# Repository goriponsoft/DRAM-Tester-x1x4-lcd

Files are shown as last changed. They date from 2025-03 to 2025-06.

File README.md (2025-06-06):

# DRAM Tester x1x4 lcd by Goripon Hardware
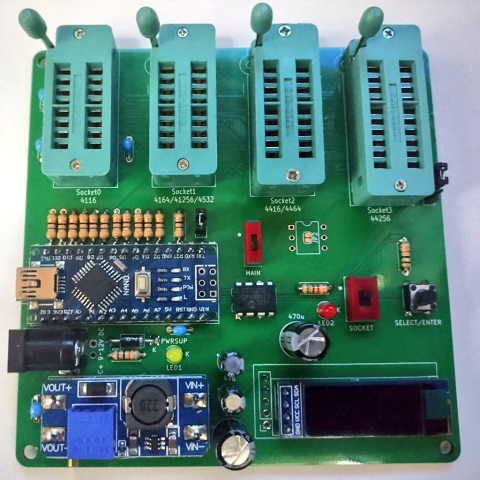
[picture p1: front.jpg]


[日本語版 README はこちら](https://github.com/goriponsoft/Dram-Tester-x1x4-lcd/blob/main/README-ja.md)

 This is a stand-alone DRAM tester compatible with 4116/4164/41256/4532/4416/4464/44256 and equipped with an LCD. Although it is not a direct fork, it is created based on [zeus074/dramtester](https://github.com/zeus074/dramtester) and [cloudree/DRAM_Tester](https://github.com/cloudree/DRAM_Tester). Thanks to the two original authors. Both of the two references are under the GPL3.0 license, so this DRAM tester will also be released under the GPL3.0 license.

 This DRAM tester was created by Goripon Hardware (the hardware division of Doujin Circle Goripon Software).

 X(old Twitter): @goriponsoft

# Components
(Check schematic/bom.xlsx as it may not match the schematic updates)
|Part Number|Parts|Quantity|
|:--|:--|--:|
|C1-C4|Unpolarized capacitor 100nF (Withstand voltage 16V or more.)|4|
|C5,C8|Polarized capacitor 470uF (Withstand voltage 16V or more.)|2|
|C6,C7|Polarized capacitor 10uF (Withstand voltage 16V or more.)|2|
|IC1|DC-DC Converter(Charge pump), 8-Pin PDIP "TJ7660"|1|
|CN1|DC Power Connector, Jack "MJ-179PH"|1|
|JP1|Pin Header 1x3 and Jumper Pin|1|
|JP2|Pin Header 1x2 and Jumper Pin|1|
|LED1|LED, D3.0mm, Yellow (Forward voltage 2.1V)|1|
|LED2|LED, D3.0mm, Green or Red (Forward voltage 2.1V)|1|
|R1-R11,R19|Resistor 47 ohm, 1/4 watt, tolerance 5%|12|
|R12,R13|Resistor 47 ohm, 1/6 watt, tolerance 5%|2|
|R14,R17|Resistor 10K ohm, 1/4 watt, tolerance 5%|2|
|R15|Resistor 1.5K ohm, 1/4 watt, required low tolerance (ex. 1%)|1|
|R16|Resistor 750 ohm, 1/4 watt, required low tolerance (ex. 1%)|1|
|R18|Resistor 5.1K ohm, 1/4 watt, tolerance 5%|1|
|S0-S1|3M Zero pressure (ZIF) socket 16pin "216-3340-00-0602J"|2|
|S2|3M Zero pressure (ZIF) socket 18pin "218-3341-00-0602J"|1|
|S3|3M Zero pressure (ZIF) socket 20pin "220-3342-00-0602J"|1|
|SW1|6x6mm Through hole & ground terminal type tactile switch "DTS-63N-V"|1|
|SW2|Switch Slide ON None ON SPDT Top Slide Thru-Hole "SS12SDP2"|1|
|SW3|Switch Slide ON None ON DPDT Top Slide Thru-Hole "SS22SDP2"|1|
|U1|Arduino Nano|1|
|U2|MT3608 DCDC Module|1|
|U3|I2C OLED Screen 0.91in. 128x32dots|1|
|-|Pin header for module installation|-|
|-|9V-12V 1A Center+ ACDC adapter|1|

# Directory
- firmware: Firmware for Arduino Nano.
- firmware/ArduinoIDE/Dram-Tester-x1x4-lcd: Firmware source code for Arduino IDE environment. You can compile and write sketches using the Arduino IDE.
- firmware/ArduinoIDE/Dram-Tester-x1x4-lcd/build: Firmware compiled binary. You can write HEX files using AVR programmer.
- firmware/PlatformIO/Dram-Tester-x1x4-lcd: Firmware source code for PlatformIO environment. You can compile using PlatformIO and write compiled binaries.
- firmware/PlatformIO/Dram-Tester-x1x4-lcd/.pio/build/Arduino_nano: Firmware compiled binary. You can write HEX files using AVR programmer.
- schematic: Schematic data for KICAD7.
- schematic/production: Gerber data for PCB ordering.

# How to assemble
Refer to the photo of the finished product on this page and solder and place the components according to the silk screen printing on the board.

For the Arduino Nano, DCDC converter board, and OLED display, first solder the headers to the components, then insert the pin headers into the board and solder them. No other special steps are required, so follow the normal assembly method for electronic circuits.

# Preparation
*For the finished products and kits we distribute, steps 1 to 6 are not necessary because the firmware is already written.

1. Connect the power supply to the board (USB connector or DC jack), turn on the main power switch, and measure the 3.3V power output of the Arduino Nano with a voltage tester and make a note of it.
2. Change "#if 0" to "#if 1" near the beginning of the setup() function in Dram-Tester-x1x4-lcd.cpp (or Dram-Tester-x1x4-lcd.ino), and replace the "3.300" part of the equation that assigns a value to the calibrationValue variable with the voltage you noted down (if you don't mind the error, you can leave it as 3.300, but the voltage check may not work correctly).
3. Connect the Arduino Nano to the PC via USB, and write the compiled sketch using the Arduino IDE, or write the HEX file using PlatformIO or an AVR writer.
4. Turn the main power switch on and off on the board, or press the reset button to start the firmware (the modified firmware will run and the voltage correction value will be written to the EEPROM).
5. Change "#if 1" in the source back to "#if 0". Note that steps 1 to 5 only need to be done the first time, and are not necessary thereafter.
6. Write the compiled sketch again using the Arduino IDE, or write the HEX file using PlatformIO or AVR writer.
7. Turn on the main power switch on the board, then turn the tri-pot resistor of the MT3608DCDC converter module while measuring the voltage with a tester to adjust it to 12V. You can also press and hold the SELECT/ENTER button while turning on or resetting the power switch to enter the setting change mode and display the voltage.
8. Set the jumper pin of JP1 (socket power LED operation). When 1-2 is shorted, the light turns on when ON, when 2-3 is shorted, the light turns on when OFF, and when the jumper pin is removed, the light turns off all the time.

# How it works
0. Connect the ACDC adapter (center positive, 9V to 12V, 1A) to the DC jack. Although it can be operated by connecting a 5V power supply or PC to the Arduino nano's USB connector, we recommend using an ACDC adapter.
1. Turn off socket power switch, then insert DRAM under test into the socket. Insert into SOCKET0 for 4116, SOCKET1 for 4164/41256/4532, SOCKET2 for 4416/4464, and SOCKET3 for 44256. *Please note that if you insert a DRAM other than 4116 type into SOCKET0, it will be damaged.
2. Turn on socket power switch, check the LCD display, and select DRAM model number by pressing SELECT/ENTER button. The socket into which the DRAM should be inserted will also be displayed on the LCD, so check that it is correct.
3. Press and hold the SELECT/ENTER button to start the test. *For safety reasons, the buttons cannot be operated while the socket power switch is off.
4. After waiting a few tens of seconds to a few minutes (depending on the amount of DRAM and test stringency settings, less if an error occurs), the results will be displayed.
5. Turn off the socket power switch and remove the tested DRAM from the socket. If you want to replace it with another DRAM after testing, please turn off the socket power switch first.

# Setting change
By holding down the SELECT/ENTER button and turning on the main power switch, you can start up in setting change mode. As with normal DRAM model selection, short press the SELECT/ENTER button to select an item, long press to confirm or change settings.

- 4bit DRAM Test: Select whether to test 4bit DRAM with priority given to speed ("Speedy") or strictly ("Strict").
- Power5V Voltage: Check the voltage of the 5V power supply and select whether to abort the test ("Check") or ignore it and continue the test ("Ignore") if the voltage is abnormal. In the case of USB power, the voltage of the power supply may drop and the test may not be performed correctly.
- Erase EEPROM: You can initialize the settings by erasing the contents of the EEPROM (values for correction, etc. remain). When erasing is complete, you will be forced to exit the settings change mode.
- View Power12V: Displays voltage of 12V power supply and voltage error. If 12V power supply voltage is not appropriate, the 4116 DRAM cannot be tested. Please reset when exiting. *Voltage cannot be displayed if the socket power is turned off.
- View Button & Power5V: Displays button test and 5V power status. Please reset when exiting.
- Save and Exit: Save the changes, exit setting change mode, and proceed to normal DRAM model number selection. Changes will not be saved unless you exit setting change mode. If you do not want to save, you can avoid saving by resetting without making a decision with this item.

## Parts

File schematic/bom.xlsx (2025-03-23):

Dram-Tester-x1x4-lcd BOM
 | Ref# | Detail | Value | Qnty
 | C1-C4 | MLC capacitor or Ceramic capacitor, radial lead, lead pitch 2.5mm | 0.1uF(100nF) 50V | 4
 | C5, C8 | ALUM capacitor, radial lead, lead pitch 3.5mm | 470uF 16V | 2
 | C6, C7 | ALUM capacitor, radial lead, lead pitch 2.0mm | 10uF 16V | 2
 | CN1 | DC jack | MJ-179PH | 1
 | D1 | General Purpose Rectifier Diode, DO-41 | 1N4007 | 1
 | IC1 | Super Charge Pump DC-to-DC Voltage Converter, DIP | TJ7660 | 1
 | JP1 | Pin Header 1x3 | - | 1
 | JP2 | Pin Header 1x2 | - | 1
 | LED1 | LED, D3.0mm, Yellow | OSY5JA3Z74A | 1
 | LED2 | LED, D3.0mm, Green | OSG5TA3Z74A | 1
 | R1-R13 | Register 1/4W, tolerance 5% | 47 ohm | 13
 | R19 | Register 1/4W, tolerance 5% | 47 ohm | 1
 | R14, R17 | Register 1/4W, tolerance 5% | 10K ohm | 2
 | R15 | Register 1/4W, low tolerance | 1.5K ohm | 1
 | R16 | Register 1/4W, low tolerance | 750 ohm | 1
 | R18 | Register 1/4W, tolerance 5% | 5.1K ohm | 1
 | S0-S1 | Zero pressure (ZIF) socket 16pin | 216-3340-00-0602J | 2
 | S2 | Zero pressure (ZIF) socket 18pin | 218-3341-00-0602J | 1
 | S3 | Zero pressure (ZIF) socket 20pin | 220-3342-00-0602J | 1
 | SW1 | 6x6mm tactile switch, through hole | DTS-63N-V | 1
 | SW2 | Slide switch, through hole, SPDT ON-ON | SS12SDP2 | 1
 | SW3 | Slide switch, through hole, DPDT ON-ON | SS22SDP2 | 1
 | U1 | Arduino Nano | - | 1
 | U2 | MT3608 DC-DC converter module | - | 1
 | U3 | OLED Screen 0.91inch, I2C SSD1306 controller, 128x32 dot | - | 1

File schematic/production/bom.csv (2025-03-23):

Designator | Footprint | Quantity | Value | LCSC Part #
C1, C2, C3, C4 | C_Disc_D3.4mm_W2.1mm_P2.50mm | 4 | 0.1u
C5, C8 | CP_Radial_D8.0mm_P3.50mm | 2 | 470u
C6, C7 | CP_Radial_D5.0mm_P2.00mm | 2 | 10u
CN1 | MJ179PH | 1 | MJ-179PH
D1 | D_DO-41_SOD81_P10.16mm_Horizontal | 1 | 1N4007
IC1 | DIP8_300mil_FineLongPad | 1 | TJ7660
JP1 | PinHeader_1x03_P2.54mm_Vertical | 1 | LEDTYP
LED1 | LED_D3.0mm | 1 | Yellow
LED2 | LED_D3.0mm | 1 | SCKTPW
R1, R10, R11, R12, R13, R2, R3, R4, R5, R6, R7, R8, R9 | R_Axial_DIN0207_L6.3mm_D2.5mm_P7.62mm_Horizontal | 13 | 47
R14, R17 | R_Axial_DIN0207_L6.3mm_D2.5mm_P7.62mm_Horizontal | 2 | 10K
R15 | R_Axial_DIN0207_L6.3mm_D2.5mm_P7.62mm_Horizontal | 1 | 1.5k
R16 | R_Axial_DIN0207_L6.3mm_D2.5mm_P7.62mm_Horizontal | 1 | 750
R18 | R_Axial_DIN0207_L6.3mm_D2.5mm_P7.62mm_Horizontal | 1 | 5.1K
S0, S1 | DIP_Socket-16_W4.3_W5.08_W7.62_W10.16_W10.9_3M_216-3340-00-0602J | 2 | ZIF Socket 16pin
S2 | DIP_Socket-18_W4.3_W5.08_W7.62_W10.16_W10.9_3M_218-3341-00-0602J | 1 | ZIF Socket 18pin
S3 | DIP_Socket-20_W4.3_W5.08_W7.62_W10.16_W10.9_3M_220-3342-00-0602J | 1 | ZIF Socket 20pin
SW1 | DTS63NV | 1 | DTS-63N-V
SW2 | SS12SDP2 | 1 | SS12SDP2
SW3 | SS22SDP2 | 1 | SS22SDP2
U1 | Arduino_Nano | 1 | Arduino Nano
U2 | MT3608_DCDC_Module | 1 | MT3608 DCDC Module
U3 | I2C_OLED_0.91in_128x32 | 1 | I2C OLED Screen 0.91inch 128x32dot

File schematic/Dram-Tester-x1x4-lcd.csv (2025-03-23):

Source: | Y:\Project\Dram-Tester-x1x4-lcd\Dram-Tester-x1x4-lcd.kicad_sch
Date: | 2025/03/17 20:05:09
Tool: | Eeschema 7.0.11
Generator: | C:\Program Files\KiCad\7.0\bin\scripting\plugins/bom_csv_grouped_by_value_with_fp.py
Component Count: | 42
Ref | Qnty | Value | Cmp name | Footprint | Description | Vendor | DNP
C1, C2, C3, C4 | 4 | 0.1u | C_Small | Capacitor_THT:C_Disc_D3.4mm_W2.1mm_P2.50mm | Unpolarized capacitor, small symbol
C5, C8 | 2 | 470u | C_Polarized_Small | Capacitor_THT:CP_Radial_D8.0mm_P3.50mm | Polarized capacitor, small symbol
C6, C7 | 2 | 10u | C_Polarized_Small | Capacitor_THT:CP_Radial_D5.0mm_P2.00mm | Polarized capacitor, small symbol
CN1 | 1 | MJ-179PH | MJ-179PH | ProjectLibrary:MJ179PH | DC Power Connector, Jack, 4 A, 1.95 mm, PCB Mount, Through Hole, J=Center-pin/S=Outer-contact
D1 | 1 | 1N4007 | 1N4007 | Diode_THT:D_DO-41_SOD81_P10.16mm_Horizontal | 1000V 1A General Purpose Rectifier Diode, DO-41
IC1 | 1 | TJ7660 | TC7660SCPA | ProjectLibrary:DIP8_300mil_FineLongPad | Microchip TC7660SCPA, DC-DC Converter, 8-Pin PDIP
JP1 | 1 | LEDTYP | Jumper_3_Open | Connector_PinHeader_2.54mm:PinHeader_1x03_P2.54mm_Vertical | Jumper, 3-pole, both open
LED1 | 1 | Yellow | LED_Small_Filled | LED_THT:LED_D3.0mm | Light emitting diode, small symbol, filled shape
LED2 | 1 | SCKTPW | LED_Small_Filled | LED_THT:LED_D3.0mm | Light emitting diode, small symbol, filled shape
R1, R2, R3, R4, R5, R6, R7, R8, R9, R10, R11, R12, R13 | 13 | 47 | R_Small | ProjectLibrary:R_Axial_DIN0207_L6.3mm_D2.5mm_P7.62mm_Horizontal | Resistor, small symbol
R14, R17 | 2 | 10K | R_Small | Resistor_THT:R_Axial_DIN0207_L6.3mm_D2.5mm_P7.62mm_Horizontal | Resistor, small symbol
R15 | 1 | 1.5k | R_Small | Resistor_THT:R_Axial_DIN0207_L6.3mm_D2.5mm_P7.62mm_Horizontal | Resistor, small symbol
R16 | 1 | 750 | R_Small | Resistor_THT:R_Axial_DIN0207_L6.3mm_D2.5mm_P7.62mm_Horizontal | Resistor, small symbol
R18 | 1 | 5.1K | R_Small | Resistor_THT:R_Axial_DIN0207_L6.3mm_D2.5mm_P7.62mm_Horizontal | Resistor, small symbol
S0, S1 | 2 | ZIF Socket 16pin | DRAM_256Kx1 | Socket:DIP_Socket-16_W4.3_W5.08_W7.62_W10.16_W10.9_3M_216-3340-00-0602J
S2 | 1 | ZIF Socket 18pin | DRAM_64Kx4 | Socket:DIP_Socket-18_W4.3_W5.08_W7.62_W10.16_W10.9_3M_218-3341-00-0602J
S3 | 1 | ZIF Socket 20pin | DRAM_256Kx4 | Socket:DIP_Socket-20_W4.3_W5.08_W7.62_W10.16_W10.9_3M_220-3342-00-0602J
SW1 | 1 | DTS-63N-V | DTS-63N-V | ProjectLibrary:DTS63NV | 6x6 Through Hole & Ground Terminal Type,TS 6MM V H=7.0 160gf BULK
SW2 | 1 | SS12SDP2 | SS12SDP2 | ProjectLibrary:SS12SDP2 | Switch, Slide,Sub Miniature,Top Actuated,SPDT, On-none-On
SW3 | 1 | SS22SDP2 | SS22SDP2 | ProjectLibrary:SS22SDP2 | Switch Slide ON None ON DPDT Top Slide 0.1A 30VDC 10000Cycles PC Pins Thru-Hole
U1 | 1 | Arduino Nano | Arduino_Nano_v3.x | Module:Arduino_Nano | Arduino Nano v3.x
U2 | 1 | MT3608 DCDC Module | MT3608_DCDC_Module | ProjectLibrary:MT3608_DCDC_Module
U3 | 1 | I2C OLED Screen 0.91inch 128x32dot | I2C_OLED_Screen_0.91_128x32 | ProjectLibrary:I2C_OLED_0.91in_128x32 | I2C OLED Screen 0.91inch 128x32dot SSD1306 controller

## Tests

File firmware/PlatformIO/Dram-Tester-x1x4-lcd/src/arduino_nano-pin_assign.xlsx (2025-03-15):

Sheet: pin assign(1)
assign | Arduino nano |  |  |  | assign
DRAM-A5 | PB5 | D13 | D12 | PB4 | DRAM-A4
3V3 | - | 3V3 | ~D11 | PB3 | DRAM-A3
no | - | AREF | ~D10 | PB2 | DRAM-A2
DRAM-DQ0/Q | PC0 | A0/D14 | ~D9 | PB1 | DRAM-A1
DRAM-DQ1/D | PC1 | A1/D15 | D8 | PB0 | DRAM-A0
DRAM-DQ2 | PC2 | A2/D16 | D7 | PD7 | DRAM-A8
DRAM-DQ3 | PC3 | A3/D17 | ~D6 | PD6 | DRAM-A7
I2C | PC4 | A4/D18 | ~D5 | PD5 | DRAM-A6
I2C | PC5 | A5/D19 | D4 | PD4 | DRAM-/RAS
Button/3V3 monitoring | - | A6 | ~D3 | PD3 | DRAM-/CAS
12V monitoring | - | A7 | D2 | PD2 | DRAM-/W
DRAM Power Supply | - | +5V | GND | - | (DRAM-/OE)
no | PC6 | RESET | RESET | PC6 | no
GND | - | GND | D0/RX | PD0 | no
AC Adaptor | - | VIN | D1/TX | PD1 | (DRAM-A9)

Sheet: pin assign(2)
PC0 | DRAM-DQ0/Q
PC1 | DRAM-DQ1/D
PC2 | DRAM-DQ2
PC3 | DRAM-DQ3
PC4 | I2C-SDA
PC5 | I2C-SCL
PC6 | (RESET)
PC7 | -
PD0 | (no assign)
PD1 | DRAM-A9
PD2 | DRAM-/W
PD3 | DRAM-/CAS
PD4 | DRAM-/RAS
PD5 | DRAM-A6
PD6 | DRAM-A7
PD7 | DRAM-A8
PB0 | DRAM-A0
PB1 | DRAM-A1
PB2 | DRAM-A2
PB3 | DRAM-A3
PB4 | DRAM-A4
PB5 | DRAM-A5
PB6 | (XTAL)
PB7 | (XTAL)

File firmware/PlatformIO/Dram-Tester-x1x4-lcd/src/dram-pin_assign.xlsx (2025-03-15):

4116 |  |  |  |  |  | 4164 typeA |  |  |  |  |  | 4416 |  |  |  |  |  | 44256
-5V | VBB | 1 | 16 | VSS | GND | ROW8/COL8 | NC | 1 | 16 | VSS | GND | GND | /G | 1 | 18 | VSS | GND | - | DQ1 | 1 | 20 | VSS | GND
- | D | 2 | 15 | /CAS | - | - | D | 2 | 15 | /CAS | - | - | DQ1 | 2 | 17 | DQ4 | - | - | DQ2 | 2 | 19 | DQ4 | -
- | /W | 3 | 14 | Q | - | - | /W | 3 | 14 | Q | - | - | DQ2 | 3 | 16 | /CAS | - | - | /W | 3 | 18 | DQ3 | -
- | /RAS | 4 | 13 | A6 | ROW6/COL6 | - | /RAS | 4 | 13 | A6 | ROW6/COL6 | - | /W | 4 | 15 | DQ3 | - | - | /RAS | 4 | 17 | /CAS | -
ROW0/COL0 | A0 | 5 | 12 | A3 | ROW3/COL3 | ROW0/COL0 | A0 | 5 | 12 | A3 | ROW3/COL3 | - | /RAS | 5 | 14 | A0 | ROW0 | - | NC | 5 | 16 | /G | GND
ROW2/COL2 | A2 | 6 | 11 | A4 | ROW4/COL4 | ROW2/COL2 | A2 | 6 | 11 | A4 | ROW4/COL4 | ROW6/COL5 | A6 | 6 | 13 | A1 | ROW1/COL0 | ROW0/COL0 | A0 | 6 | 15 | A8 | ROW8/COL8
ROW1/COL1 | A1 | 7 | 10 | A5 | ROW5/COL5 | ROW1/COL1 | A1 | 7 | 10 | A5 | ROW5/COL5 | ROW5/COL4 | A5 | 7 | 12 | A2 | ROW2/COL1 | ROW1/COL1 | A1 | 7 | 14 | A7 | ROW7/COL7
+12V | VDD | 8 | 9 | VCC | +5V | +5V | VDD | 8 | 9 | A7 | ROW7/COL7 | ROW4/COL3 | A4 | 8 | 11 | A3 | ROW3/COL2 | ROW2/COL2 | A2 | 8 | 13 | A6 | ROW6/COL6
 |  |  |  |  |  |  |  |  |  |  |  | +5V | VDD | 9 | 10 | A7 | ROW7 | ROW3/COL3 | A3 | 9 | 12 | A5 | ROW5/COL5
 |  |  |  |  |  | 4164 typeB |  |  |  |  |  |  |  |  |  |  |  | +5V | VCC | 10 | 11 | A4 | ROW4/COL4
 |  |  |  |  |  | ROW8=H/COL8=H | /RFSH | 1 | 16 | VSS | GND | 4464
 |  |  |  |  |  | - | D | 2 | 15 | /CAS | - | GND | /G | 1 | 18 | VSS | GND | 4400
 |  |  |  |  |  | - | /W | 3 | 14 | Q | - | - | DQ1 | 2 | 17 | DQ4 | - | - | DQ1 | 1 | 20 | VSS | GND
 |  |  |  |  |  | - | /RAS | 4 | 13 | A6 | ROW6/COL6 | - | DQ2 | 3 | 16 | /CAS | - | - | DQ2 | 2 | 19 | DQ4 | -
 |  |  |  |  |  | ROW0/COL0 | A0 | 5 | 12 | A3 | ROW3/COL3 | - | /W | 4 | 15 | DQ3 | - | - | /W | 3 | 18 | DQ3 | -
 |  |  |  |  |  | ROW2/COL2 | A2 | 6 | 11 | A4 | ROW4/COL4 | - | /RAS | 5 | 14 | A0 | ROW0/COL0 | - | /RAS | 4 | 17 | /CAS | -
 |  |  |  |  |  | ROW1/COL1 | A1 | 7 | 10 | A5 | ROW5/COL5 | ROW6/COL6 | A6 | 6 | 13 | A1 | ROW1/COL1 | ROW9/COL9 | A9 | 5 | 16 | /G | GND
 |  |  |  |  |  | +5V | VDD | 8 | 9 | A7 | ROW7/COL7 | ROW5/COL5 | A5 | 7 | 12 | A2 | ROW2/COL2 | ROW0/COL0 | A0 | 6 | 15 | A8 | ROW8/COL8
 |  |  |  |  |  |  |  |  |  |  |  | ROW4/COL4 | A4 | 8 | 11 | A3 | ROW3/COL3 | ROW1/COL1 | A1 | 7 | 14 | A7 | ROW7/COL7
 |  |  |  |  |  | 41256 |  |  |  |  |  | +5V | VDD | 9 | 10 | A7 | ROW7/COL7 | ROW2/COL2 | A2 | 8 | 13 | A6 | ROW6/COL6
 |  |  |  |  |  | ROW8/COL8 | A8 | 1 | 16 | VSS | GND |  |  |  |  |  |  | ROW3/COL3 | A3 | 9 | 12 | A5 | ROW5/COL5
 |  |  |  |  |  | - | D | 2 | 15 | /CAS | - |  |  |  |  |  |  | +5V | VCC | 10 | 11 | A4 | ROW4/COL4
 |  |  |  |  |  | - | /W | 3 | 14 | Q | -
 |  |  |  |  |  | - | /RAS | 4 | 13 | A6 | ROW6/COL6
 |  |  |  |  |  | ROW0/COL0 | A0 | 5 | 12 | A3 | ROW3/COL3
 |  |  |  |  |  | ROW2/COL2 | A2 | 6 | 11 | A4 | ROW4/COL4
 |  |  |  |  |  | ROW1/COL1 | A1 | 7 | 10 | A5 | ROW5/COL5
 |  |  |  |  |  | +5V | VDD | 8 | 9 | A7 | ROW7/COL7
 |  |  |  |  |  | 4532L
 |  |  |  |  |  | ROW8/COL8 | NC | 1 | 16 | VSS | GND
 |  |  |  |  |  | - | D | 2 | 15 | /CAS | -
 |  |  |  |  |  | - | /W | 3 | 14 | Q | -
 |  |  |  |  |  | - | /RAS | 4 | 13 | A6 | ROW6/COL6
 |  |  |  |  |  | ROW0/COL0 | A0 | 5 | 12 | A3 | ROW3/COL3
 |  |  |  |  |  | ROW2/COL2 | A2 | 6 | 11 | A4 | ROW4/COL4
 |  |  |  |  |  | ROW1/COL1 | A1 | 7 | 10 | A5 | ROW5/COL5
 |  |  |  |  |  | +5V | VDD | 8 | 9 | A7 | ROW7/COL7=L
 |  |  |  |  |  | 4532H
 |  |  |  |  |  | ROW8/COL8 | NC | 1 | 16 | VSS | GND
 |  |  |  |  |  | - | D | 2 | 15 | /CAS | -
 |  |  |  |  |  | - | /W | 3 | 14 | Q | -
 |  |  |  |  |  | - | /RAS | 4 | 13 | A6 | ROW6/COL6
 |  |  |  |  |  | ROW0/COL0 | A0 | 5 | 12 | A3 | ROW3/COL3
 |  |  |  |  |  | ROW2/COL2 | A2 | 6 | 11 | A4 | ROW4/COL4
 |  |  |  |  |  | ROW1/COL1 | A1 | 7 | 10 | A5 | ROW5/COL5
 |  |  |  |  |  | +5V | VDD | 8 | 9 | A7 | ROW7/COL7=H

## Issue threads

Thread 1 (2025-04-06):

Just a question...

solidhit2, 2025-04-06:
I came across this project recently and I'm about to order the PCB from PCBWay. Is there something I should be careful of before I make my order? Finally, I would like to know if it supports the Marching Memory testing algorithms or if you intend to implement such algorithms in the future? By the way, I wish every success for this project... the retro community needs a memory tester for as many old memory chips as possible!

solidhit2, 2025-04-28:
Not a real issue!

Closed 2025-04-28.

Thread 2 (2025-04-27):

Wrong voltage measurement...

solidhit2, 2025-04-27:
I assembled the tester soon after my PCBs arrived from PCBWAY. When I tried to run the tester I received a message that 5V failed. Measuring right at the socket with a multi-meter, I get 5V exactly (I also get 11.94 for the 12V and -5V exactly for the -5V for socket0). I went to the settings menu and deactivated the 5V check and the tester works. In the settings menu I saw that Arduino measures my 5V as 4.5V and my 12V as 10.6V. Why is this happening, is there anything I can do to help it measure right?

For your information, my Arduino nano is not the original, I bought it from ALIEXPRESS as an "Arduino nano v3". Other than that the tests seem to work fine although I don't have any bad chips at the moment.

Lastly, I use a PD trigger module to power the PCB similar to PDT006. It produces a very clean voltage and operates at 9V exactly.

I'd be grateful for any advice!

goriponsoft, 2025-04-28:
Sorry.

The +5V power supply voltage is measured using a value corrected based on the Arduino Nano's +3.3V power supply voltage as the standard, but if nothing is done, it will operate as if +3.3V is the standard value, which may result in an incorrect voltage measurement.

To operate correctly if the measurement is incorrect, it is necessary to write the value used for voltage correction to the EEPROM, but this procedure was not mentioned.

I have added instructions for writing the values   needed for voltage correction to the EEPROM in the Preparation section of the README, so please refer to that.

________________________________
差出人: solidhit2 ***@***.***>
送信日時: 2025年4月28日 6:31
宛先: goriponsoft/DRAM-Tester-x1x4-lcd ***@***.***>
CC: Subscribed ***@***.***>
件名: [goriponsoft/DRAM-Tester-x1x4-lcd] Wrong voltage measurement... (Issue #2)

[https://avatars.githubusercontent.com/u/157960411?s=20&v=4]solidhit2 created an issue (goriponsoft/DRAM-Tester-x1x4-lcd#2)<https://github.com/goriponsoft/DRAM-Tester-x1x4-lcd/issues/2>

I assembled the tester soon after my PCBs arrived from PCBWAY. When I tried to run the tester I received a message that 5V failed. Measuring right at the socket with a multi-meter, I get 5V exactly (I also get 11.94 for the 12V and -5V exactly for the -5V for socket0). I went to the settings menu and deactivated the 5V check and the tester works. In the settings menu I saw that Arduino measures my 5V as 4.5V and my 12V as 10.6V. Why is this happening, is there anything I can do to help it measure right?

For your information, my Arduino nano is not the original, I bought it from ALIEXPRESS as an "Arduino nano v3". Other than that the tests seem to work fine although I don't have any bad chips at the moment.

Lastly, I use a PD trigger module to power the PCB similar to PDT006. It produces a very clean voltage and operates at 9V exactly.

I'd be grateful for any advice!

—
Reply to this email directly, view it on GitHub<https://github.com/goriponsoft/DRAM-Tester-x1x4-lcd/issues/2>, or unsubscribe<https://github.com/notifications/unsubscribe-auth/AAX3SQYVHZN5VGP6ZUQM5DT23VEBRAVCNFSM6AAAAAB37AZWKGVHI2DSMVQWIX3LMV43ASLTON2WKOZTGAZDGMZTGM4DQMY>.
You are receiving this because you are subscribed to this thread.Message ID: ***@***.***>

solidhit2, 2025-04-28:
Thank you for the quick response. I did what was mentioned in the readme and now the tester detects voltage properly. Just one remark. In your code you have the line "#define VOLTAGE_3V3_MAX 3.6". In my case, two of my five nano boards measured ~3.68V which caused your code to ignore my value and revert to 3.3V. I had to change the above line to "#define VOLTAGE_3V3_MAX 3.7". After that, everything worked as it should.

Since you went to the trouble of explaining how to make nano properly measure voltage, perhaps you could add some clarifications about J1 and J2 located below the oled display (I figured that out myself) and JP2 which enables A9. What is A9, when do we close the jumper and when we don't etc...

I hope in the future you may be able to add the advanced marching algorithm which can catch any combination of memory errors.

goriponsoft, 2025-04-29:
It's strange that 3.3V is measured at 3.6V or higher.

I think an error of 10% or more is abnormal (+10% voltage is 3.63V), but there are no devices on the board that directly use the 3.3V power supply, so it shouldn't be a problem.

A9 is a signal used to test 1M x 4bit (4400 type) DRAM with Socket3, and this function is disabled in the published source code.

A9 is also used as the TX signal (PD1) used for USB connection to the PC, so it was assumed that it would be open when writing firmware, but so far there have been no problems with writing firmware even if it is closed.

To be able to test 4400 type DRAM, uncomment the following line near the beginning of "Dram-Tester-x1x4-lcd.h" (or "Dram-Tester-x1x4-lcd.ino") and build it.

//#define _BUS_A9_ENABLE
//#define _4M_DRAM_ENABLE

Thank you for your request for a test algorithm. We will consider responding to your request, but since this tester is open source, you can also modify it yourself.

________________________________
差出人: solidhit2 ***@***.***>
送信日r: 2025年4月29日 0:52
宛先: goriponsoft/DRAM-Tester-x1x4-lcd ***@***.***>
CC: goriponsoft ***@***.***>; Comment ***@***.***>
件名: Re: [goriponsoft/DRAM-Tester-x1x4-lcd] Wrong voltage measurement... (Issue #2)

[https://avatars.githubusercontent.com/u/157960411?s=20&v=4]solidhit2 left a comment (goriponsoft/DRAM-Tester-x1x4-lcd#2)<https://github.com/goriponsoft/DRAM-Tester-x1x4-lcd/issues/2#issuecomment-2835713360>

Thank you for the quick response. I did what was mentioned in the readme and now the tester detects voltage properly. Just one remark. In your code you have the line "#define VOLTAGE_3V3_MAX 3.6". In my case, two of my five nano boards measured ~3.68V which caused your code to ignore my value and revert to 3.3V. I had to change the above line to "#define VOLTAGE_3V3_MAX 3.7". After that, everything worked as it should.

Since you went to the trouble of explaining how to make nano properly measure voltage, perhaps you could add some clarifications about J1 and J2 located below the oled display (I figured that out myself) and JP2 which enables A9. What is A9, when do we close the jumper and when we don't etc...

I hope in the future you may be able to add the advanced marching algorithm which can catch any combination of memory errors.

―
Reply to this email directly, view it on GitHub<https://github.com/goriponsoft/DRAM-Tester-x1x4-lcd/issues/2#issuecomment-2835713360>, or unsubscribe<https://github.com/notifications/unsubscribe-auth/AAX3SQ3HROHPBEXWIQ6NWKL23ZFELAVCNFSM6AAAAAB37AZWKGVHI2DSMVQWIX3LMV43OSLTON2WKQ3PNVWWK3TUHMZDQMZVG4YTGMZWGA>.
You are receiving this because you commented.Message ID: ***@***.***>

Closed 2025-04-29.

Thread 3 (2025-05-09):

Negative voltage possibly present even when socket power switch is off.

solidhit2, 2025-05-09:
I've been using the tester to test more than a 100 41256 memory chips and and I came across this issue. The way I work is: socket power off, put the 41256 chip in socket1, socket power on, button to start testing. This happens in quick succession because there are a lot of chips waiting to be tested. Well, testing one particular chip, I inserted the chip in socket 0 with socket power off! I instantly realized what I had done and took the chip out of socket0, inserted in in socket1, turned socket power on, started the test and the chip was bad. I found it suspicious so I tested the voltages in socket0 soon as I turned off socket power. Well, 5v and 12v were instantly 0 but with -5v, I measured ~-4.x. Turns out, -5v drop to 0 very slowly.

goriponsoft, 2025-05-12:
I was not aware of this behavior.

Maybe there are too many electrolytic capacitors.
Properly removing one or both of the two 470uF electrolytic capacitors may improve the situation.
________________________________
差出人: solidhit2 ***@***.***>
送信日時: 2025年5月9日 23:52
宛先: goriponsoft/DRAM-Tester-x1x4-lcd ***@***.***>
CC: Subscribed ***@***.***>
件名: [goriponsoft/DRAM-Tester-x1x4-lcd] Negative voltage possibly present even when socket power switch is off. (Issue #3)

[https://avatars.githubusercontent.com/u/157960411?s=20&v=4]solidhit2 created an issue (goriponsoft/DRAM-Tester-x1x4-lcd#3)<https://github.com/goriponsoft/DRAM-Tester-x1x4-lcd/issues/3>

I've been using the tester to test more than a 100 41256 memory chips and and I came across this issue. The way I work is: socket power off, put the 41256 chip in socket1, socket power on, button to start testing. This happens in quick succession because there are a lot of chips waiting to be tested. Well, testing one particular chip, I inserted the chip in socket 0 with socket power off! I instantly realized what I had done and took the chip out of socket0, inserted in in socket1, turned socket power on, started the test and the chip was bad. I found it suspicious so I tested the voltages in socket0 soon as I turned off socket power. Well, 5v and 12v were instantly 0 but with -5v, I measured ~-4.x. Turns out, -5v drop to 0 very slowly.

—
Reply to this email directly, view it on GitHub<https://github.com/goriponsoft/DRAM-Tester-x1x4-lcd/issues/3>, or unsubscribe<https://github.com/notifications/unsubscribe-auth/AAX3SQ3TM64VPWRNDG7D75T25S6JLAVCNFSM6AAAAAB4ZITHD2VHI2DSMVQWIX3LMV43ASLTON2WKOZTGA2TENBSGEYDSMY>.
You are receiving this because you are subscribed to this thread.Message ID: ***@***.***>

solidhit2, 2025-05-12:
OK, but should they be removed? Aren't they used for other things?

solidhit2, 2025-05-14:
Thank you for your response, let me tell you what I have...

I have the latest revision of the board, there are no capacitor names on the silkscreen, so I will try to figure things out taking measurements on an actual PCB and studying the schematic.

My board has positions for four electrolytic caps, two are 10uf and the other two are 470uf as written on the silkscreen.

I have a 470uf cap. between Arduino 5VDC output and GND, according to the schematic, this is C5.

I have a 10uf cap. between the VOUT of TJ7660 and GND. According to the schematic, this is C6.

I have a 10uf cap. between the CAP+ and CAP-  legs of TJ7660, according to the schematic, this is C7.

I have a 470uf cap. between PIN2 of the socket power switch and GND, according to the schematic, this is C8.

These are all. My C6 is already 10uf, I have no caps. at 47uf and I don't have a C9.

solidhit2, 2025-05-15:
I took the liberty and removed my C8 from the board as it matched the description of your C9 capacitor. The behaviour of the -5v when switch power goes off, barely changed, still residual voltage ~3-4v dropping slowly. Also, now whenever I switch the socket power on, Arduino resets (one time) before it becomes responsive again. This happens whether there is a chip in a socket or not!

goriponsoft, 2025-06-06:
If the board resets when the socket switch is turned on, the current capacity of the ACDC adapter may be insufficient. A current capacity of 1A (1000mA) or more is required.

The power supplied from the Arduino Nano's USB connector cannot meet this current capacity, so an ACDC adapter is required (USB can only supply a maximum of 500mA).

I added a 470uF electrolytic capacitor to solve this problem, but it had no effect, so it is now a candidate for removal.

Regarding the capacitor part numbers, we were explaining about the Revision 2 board, but the version currently published on GitHub is Revision 3, so the 47uF electrolytic capacitor has been changed to 10uF and other minor corrections have been made.
________________________________
差出人: solidhit2 ***@***.***>
送信日r: 2025年5月16日 6:03
宛先: goriponsoft/DRAM-Tester-x1x4-lcd ***@***.***>
CC: goriponsoft ***@***.***>; Comment ***@***.***>
件名: Re: [goriponsoft/DRAM-Tester-x1x4-lcd] Negative voltage possibly present even when socket power switch is off. (Issue #3)

[https://avatars.githubusercontent.com/u/157960411?s=20&v=4]solidhit2 left a comment (goriponsoft/DRAM-Tester-x1x4-lcd#3)<https://github.com/goriponsoft/DRAM-Tester-x1x4-lcd/issues/3#issuecomment-2885048256>

I took the liberty and removed my C8 from the board as it matched the description of your C9 capacitor. The behaviour of the -5v when switch power goes off, barely changed, still residual voltage ~3-4v dropping slowly. Also, now whenever I switch the socket power on, Arduino resets (one time) before it becomes responsive again. This happens whether there is a chip in a socket or not!

―
Reply to this email directly, view it on GitHub<https://github.com/goriponsoft/DRAM-Tester-x1x4-lcd/issues/3#issuecomment-2885048256>, or unsubscribe<https://github.com/notifications/unsubscribe-auth/AAX3SQ2EKMBA3WL3FFRPAVL26T6LJAVCNFSM6AAAAAB4ZITHD2VHI2DSMVQWIX3LMV43OSLTON2WKQ3PNVWWK3TUHMZDQOBVGA2DQMRVGY>.
You are receiving this because you commented.Message ID: ***@***.***>

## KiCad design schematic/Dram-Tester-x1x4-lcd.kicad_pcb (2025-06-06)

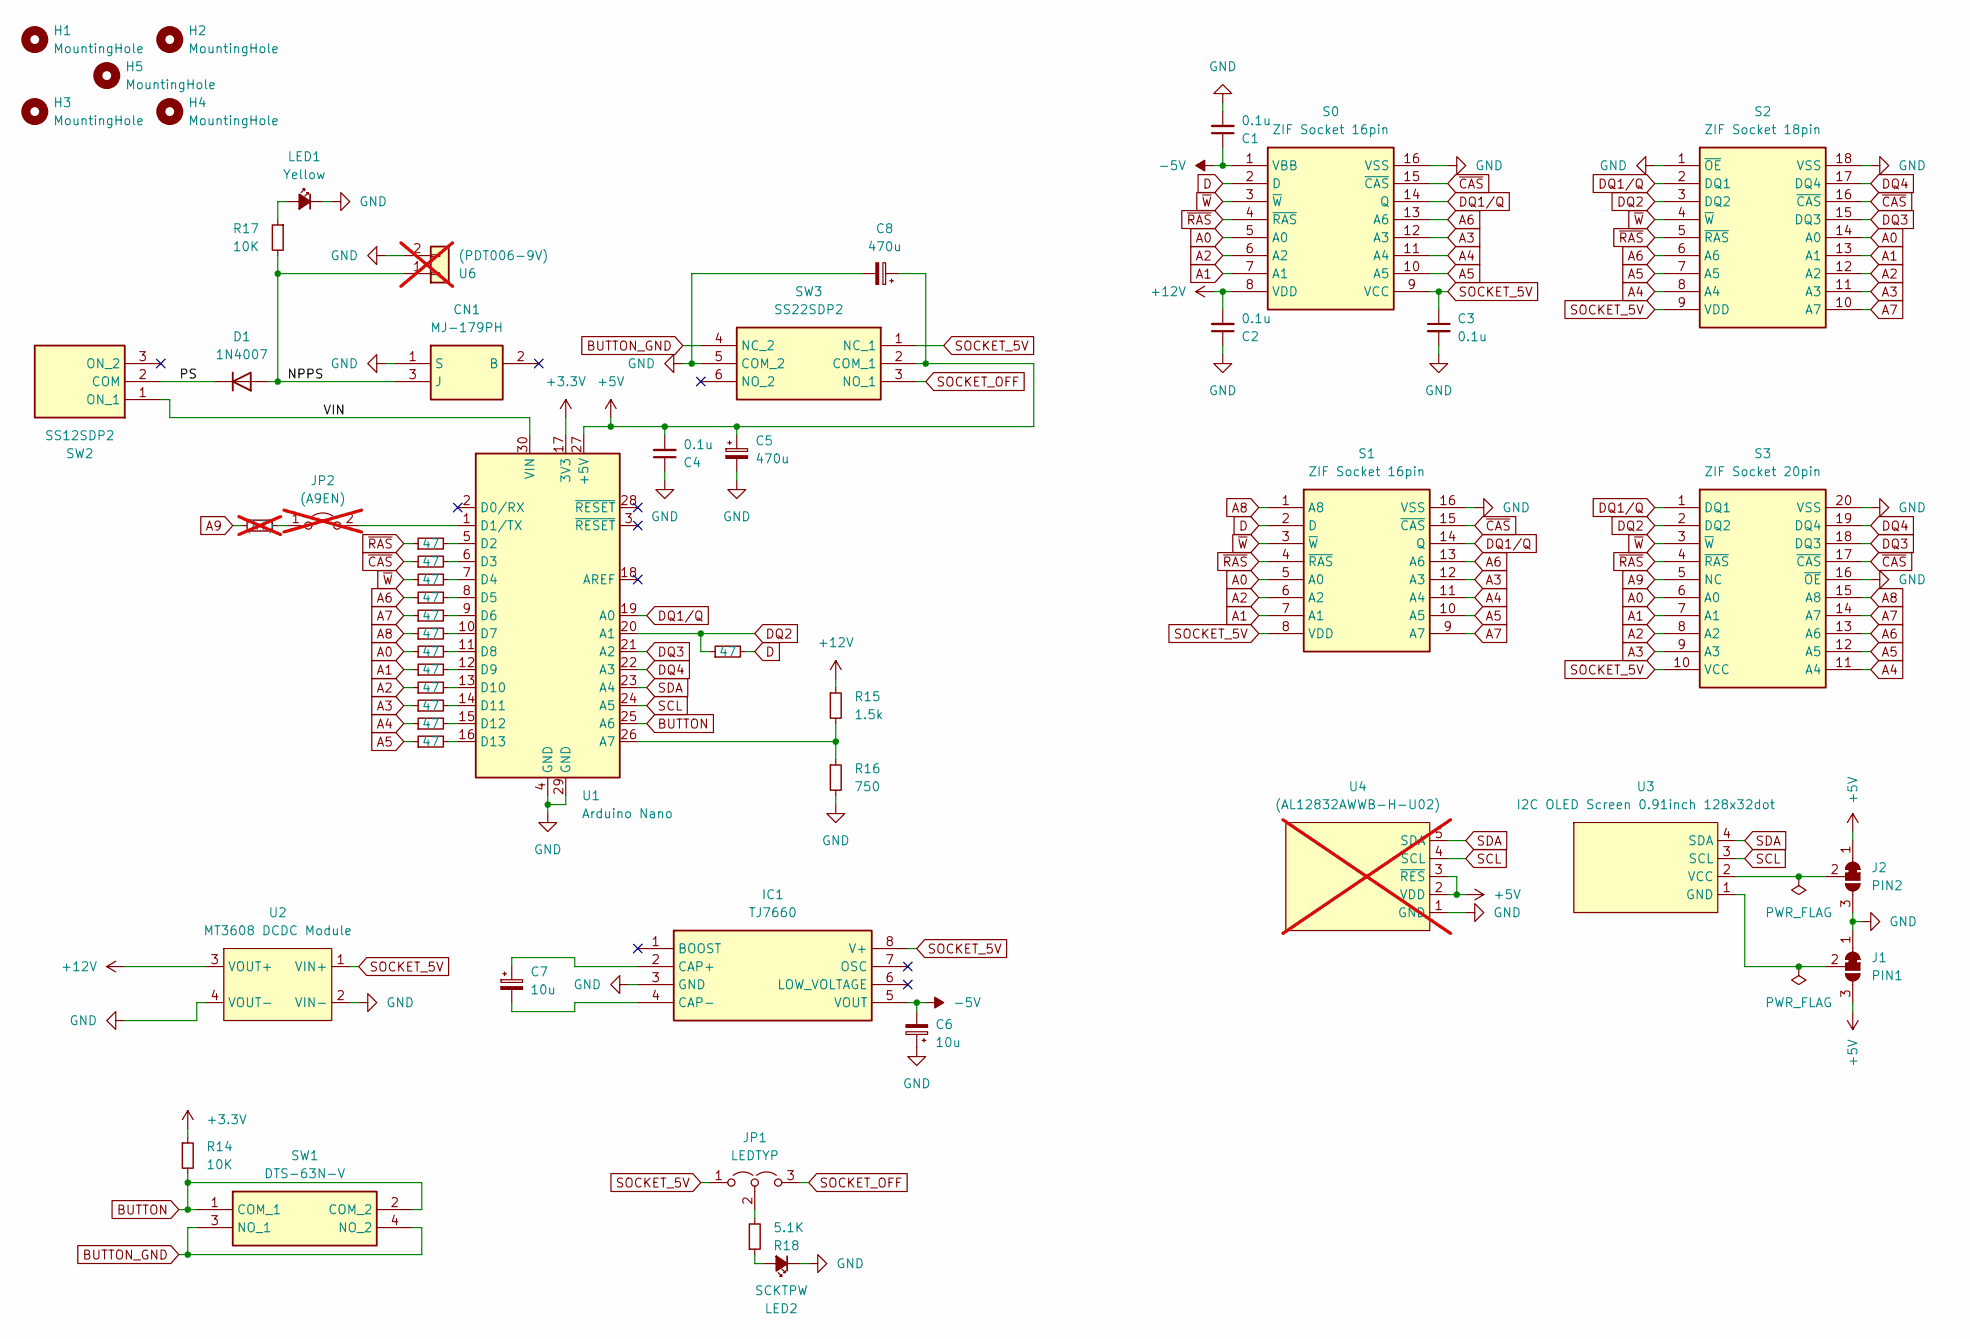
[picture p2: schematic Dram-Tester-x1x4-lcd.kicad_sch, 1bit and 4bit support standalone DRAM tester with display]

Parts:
C1, C2, C3, C4: 0.1u; C_Disc_D3.4mm_W2.1mm_P2.50mm
C5, C8: 470u; CP_Radial_D8.0mm_P3.50mm
C6, C7: 10u; CP_Radial_D5.0mm_P2.00mm
CN1: MJ-179PH; MJ179PH; Manufacturer_Part_Number MJ-179PH
D1: 1N4007; D_DO-41_SOD81_P10.16mm_Horizontal
H1, H2, H3, H4, H5: MountingHole; MountingHole_3.2mm_M3
IC1: TJ7660; DIP8_300mil_FineLongPad; Manufacturer_Part_Number TC7660SCPA; Mouser Part Number 579-TC7660SCPA
J1: PIN1; SolderJumper-3_P1.3mm_Bridged12_RoundedPad1.0x1.5mm
J2: PIN2; SolderJumper-3_P1.3mm_Bridged12_RoundedPad1.0x1.5mm
JP1: LEDTYP; PinHeader_1x03_P2.54mm_Vertical
JP2: (A9EN); PinHeader_1x02_P2.54mm_Vertical; not fitted
LED1: Yellow; LED_D3.0mm
LED2: SCKTPW; LED_D3.0mm
R1, R2, R3, R4, R5, R6, R7, R8, R9, R10, R11, R12, R13: 47; R_Axial_DIN0207_L6.3mm_D2.5mm_P7.62mm_Horizontal
R14, R17: 10K; R_Axial_DIN0207_L6.3mm_D2.5mm_P7.62mm_Horizontal
R15: 1.5k; R_Axial_DIN0207_L6.3mm_D2.5mm_P7.62mm_Horizontal
R16: 750; R_Axial_DIN0207_L6.3mm_D2.5mm_P7.62mm_Horizontal
R18: 5.1K; R_Axial_DIN0207_L6.3mm_D2.5mm_P7.62mm_Horizontal
R19: (47); R_Axial_DIN0207_L6.3mm_D2.5mm_P7.62mm_Horizontal; not fitted
S0, S1: ZIF Socket 16pin; DIP_Socket-16_W4.3_W5.08_W7.62_W10.16_W10.9_3M_216-3340-00-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
S2: ZIF Socket 18pin; DIP_Socket-18_W4.3_W5.08_W7.62_W10.16_W10.9_3M_218-3341-00-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
S3: ZIF Socket 20pin; DIP_Socket-20_W4.3_W5.08_W7.62_W10.16_W10.9_3M_220-3342-00-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
SW1: DTS-63N-V; DTS63NV; Manufacturer_Part_Number DTS-63N-V; Mouser Part Number 113-DTS-63N-V
SW2: SS12SDP2; Manufacturer_Part_Number SS12SDP2; Mouser Part Number 633-SS12SDP2
SW3: SS22SDP2; Manufacturer_Part_Number SS22SDP2; Mouser Part Number 633-SS22SDP2
U1: Arduino Nano; Arduino_Nano
U2: MT3608 DCDC Module; MT3608_DCDC_Module
U3: I2C OLED Screen 0.91inch 128x32dot; I2C_OLED_0.91in_128x32
U4: (AL12832AWWB-H-U02); AL12832AWWB-H-U02; not fitted
U6: (PDT006-9V); PinHeader_1x02_P2.54mm_Vertical; not fitted

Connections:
+3.3V: R14.1, U1.17 (3V3)
+5V: C4.2, C5.1, C8.1, J1.3 (B), J2.1 (A), SW3.2 (COM_1), U1.27 (+5V), U4.2 (VDD), U4.3 (~RES)
+12V: C2.2, R15.1, S0.8 (VDD), U2.3 (VOUT+)
-5V: C1.1, C6.2, IC1.5 (VOUT), S0.1 (VBB)
/NPPS: CN1.3 (J), D1.2 (A), R17.2, U6.1
/PS: D1.1 (K), SW2.2 (COM)
/VIN: SW2.1 (ON_1), U1.30 (VIN)
A0: R7.1, S0.5 (A0), S1.5 (A0), S2.14 (A0), S3.6 (A0)
A1: R8.1, S0.7 (A1), S1.7 (A1), S2.13 (A1), S3.7 (A1)
A2: R9.1, S0.6 (A2), S1.6 (A2), S2.12 (A2), S3.8 (A2)
A3: R10.1, S0.12 (A3), S1.12 (A3), S2.11 (A3), S3.9 (A3)
A4: R11.1, S0.11 (A4), S1.11 (A4), S2.8 (A4), S3.11 (A4)
A5: R12.1, S0.10 (A5), S1.10 (A5), S2.7 (A5), S3.12 (A5)
A6: R4.1, S0.13 (A6), S1.13 (A6), S2.6 (A6), S3.13 (A6)
A7: R5.1, S1.9 (A7), S2.10 (A7), S3.14 (A7)
A8: R6.1, S1.1 (A8), S3.15 (A8)
A9: R19.1, S3.5 (NC)
BUTTON: R14.2, SW1.1 (COM_1), SW1.2 (COM_2), U1.25 (A6)
BUTTON_GND: SW1.3 (NO_1), SW1.4 (NO_2), SW3.4 (NC_2)
D: R13.2, S0.2 (D), S1.2 (D)
DQ1/Q: S0.14 (Q), S1.14 (Q), S2.2 (DQ1), S3.1 (DQ1), U1.19 (A0)
DQ2: R13.1, S2.3 (DQ2), S3.2 (DQ2), U1.20 (A1)
DQ3: S2.15 (DQ3), S3.18 (DQ3), U1.21 (A2)
DQ4: S2.17 (DQ4), S3.19 (DQ4), U1.22 (A3)
GND: C1.2, C2.1, C3.2, C4.1, C5.2, C6.1, C8.2, CN1.1 (S), IC1.3 (GND), J1.1 (A), J2.3 (B), LED1.1 (K), LED2.1 (K), R16.2, S0.16 (VSS), S1.16 (VSS), S2.1 (~OE), S2.18 (VSS), S3.16 (~OE), S3.20 (VSS), SW3.5 (COM_2), U1.4 (GND), U1.29 (GND), U2.2 (VIN-), U2.4 (VOUT-), U4.1 (GND), U6.2
unnamed: C7.1, IC1.2 (CAP+)
unnamed: C7.2, IC1.4 (CAP-)
unnamed: J1.2 (C), U3.1 (GND)
unnamed: J2.2 (C), U3.2 (VCC)
unnamed: JP1.2 (C), R18.2
unnamed: JP2.1 (A), R19.2
unnamed: JP2.2 (B), U1.1 (D1/TX)
unnamed: LED1.2 (A), R17.1
unnamed: LED2.2 (A), R18.1
unnamed: R15.2, R16.1, U1.26 (A7)
unnamed: R1.2, U1.5 (D2)
unnamed: R2.2, U1.6 (D3)
unnamed: R3.2, U1.7 (D4)
unnamed: R4.2, U1.8 (D5)
unnamed: R5.2, U1.9 (D6)
unnamed: R6.2, U1.10 (D7)
unnamed: R7.2, U1.11 (D8)
unnamed: R8.2, U1.12 (D9)
unnamed: R9.2, U1.13 (D10)
unnamed: R10.2, U1.14 (D11)
unnamed: R11.2, U1.15 (D12)
unnamed: R12.2, U1.16 (D13)
SCL: U1.24 (A5), U3.3 (SCL), U4.4 (SCL)
SDA: U1.23 (A4), U3.4 (SDA), U4.5 (SDA)
SOCKET_5V: C3.1, IC1.8 (V+), JP1.1 (A), S0.9 (VCC), S1.8 (VDD), S2.9 (VDD), S3.10 (VCC), SW3.1 (NC_1), U2.1 (VIN+)
SOCKET_OFF: JP1.3 (B), SW3.3 (NO_1)
~CAS: R2.1, S0.15 (~CAS), S1.15 (~CAS), S2.16 (~CAS), S3.17 (~CAS)
~RAS: R1.1, S0.4 (~RAS), S1.4 (~RAS), S2.5 (~RAS), S3.4 (~RAS)
~W: R3.1, S0.3 (~W), S1.3 (~W), S2.4 (~W), S3.3 (~W)

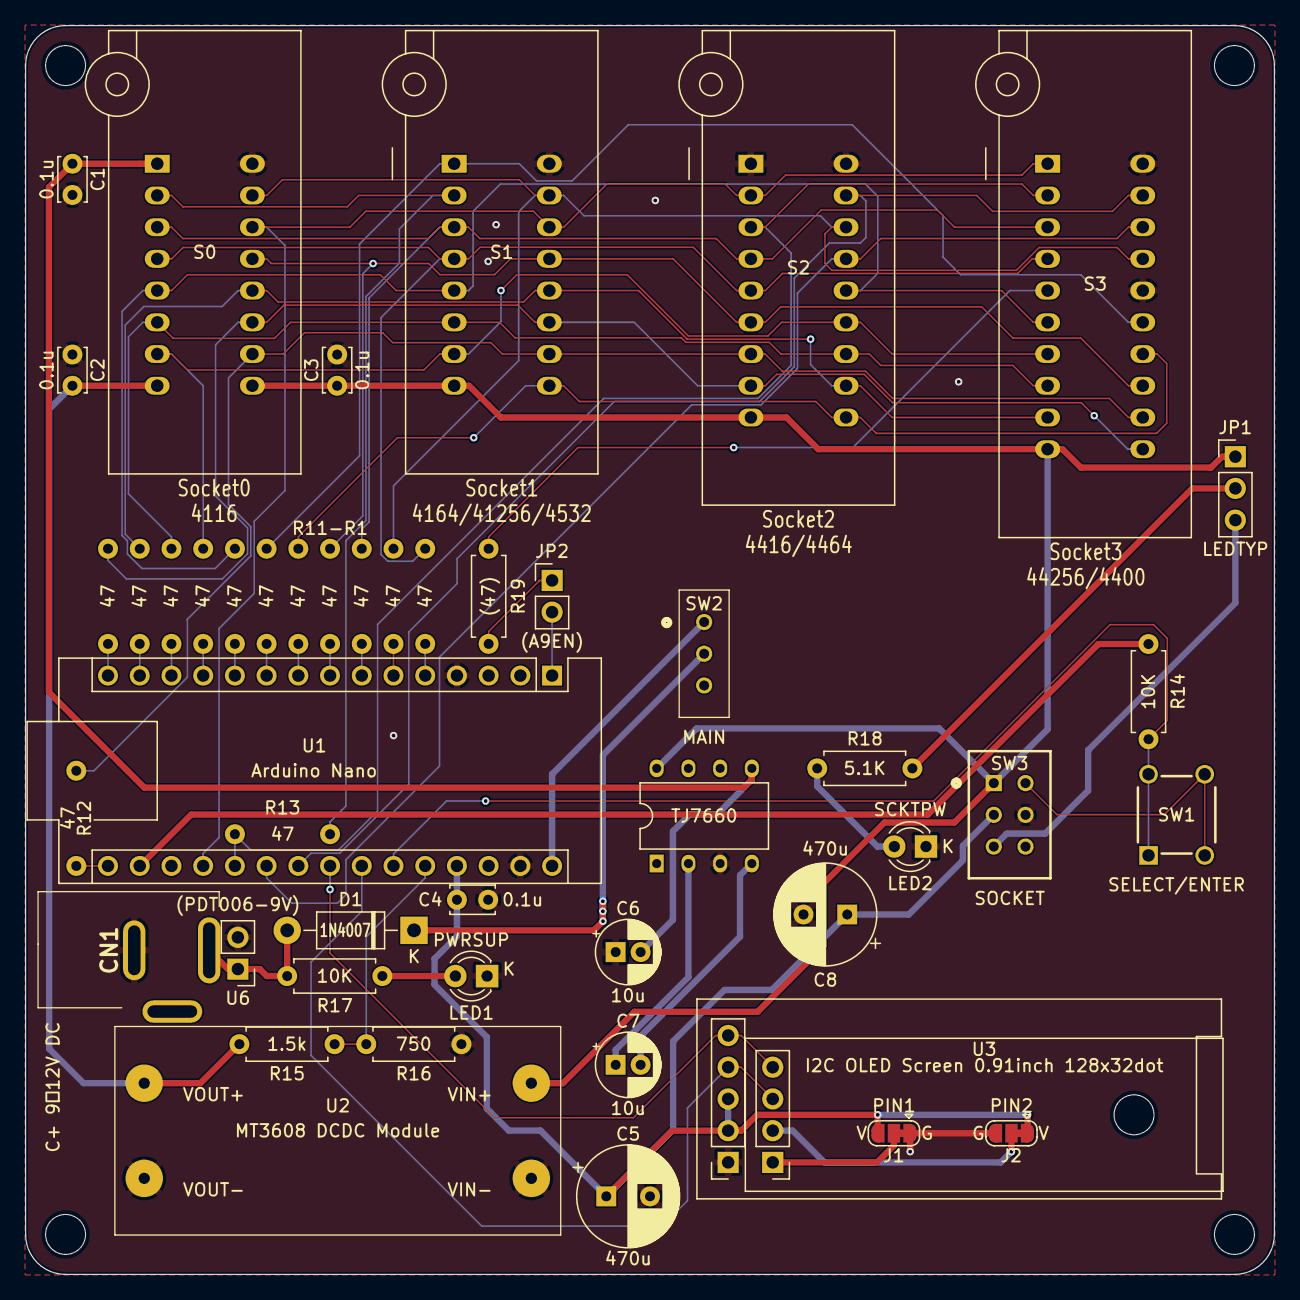
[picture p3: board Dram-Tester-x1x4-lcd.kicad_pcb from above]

Board: 2 copper layers, 100.0 x 100.0 mm, 53 parts (0 on the bottom side), 54 nets.

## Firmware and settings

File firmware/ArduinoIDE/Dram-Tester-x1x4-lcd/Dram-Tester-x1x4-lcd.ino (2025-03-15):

#include <Arduino.h>
#include <U8g2lib.h>
#include <Wire.h>
#include <EEPROM.h>

// #define _DEBUG			// Debug Function enable
// #define _DEMO_MODE		// Demo Mode firmware
// #define _BUS_A9_ENABLE  // Adress bus bit9 (PD1) enable
// #define _4M_DRAM_ENABLE  // 4M(1024Kx4) DRAM support enable. (_BUS_A9_ENABLE required.)

#define VERSION_STRING "1.0.0"
#define NAME_STRING "DRAM-Tester"
#define SUBNAME_STRING "x1/x4"

#define MIN_DRAMCONF 0
#define DRAMCONF_16X1 0
#define DRAMCONF_64X1 1
#define DRAMCONF_32X1L 2
#define DRAMCONF_32X1H 3
#define DRAMCONF_256X1 4
#define MAX_DRAMCONF_1BIT 4
#define DRAMCONF_16X4 5
#define DRAMCONF_64X4 6
#define DRAMCONF_256X4 7
#ifndef _4M_DRAM_ENABLE
#define MAX_DRAMCONF 7
#else
#define DRAMCONF_1024X4 8
#define MAX_DRAMCONF 8
#endif

#define SCENE_SETTING_SELECT_ENTER 0
#define SCENE_SETTING_SELECT 1
#define SCENE_VIEW_12V 2
#define SCENE_VIEW_BTN 3
#define SCENE_DRAMCONF_SELECT_ENTER 4
#define SCENE_DRAMCONF_SELECT 5
#define SCENE_DRAM_TEST_ENTER 6
#define SCENE_DRAM_TEST 7

#define MIN_SETTINGMODE 0
#define SETTINGMODE_TESTTYPE_CHG 0
#define SETTINGMODE_POWSRCCHK_CHG 1
#define SETTINGMODE_EEPROM_ERASE 2
#define SETTINGMODE_POWER12V_VIEW 3
#define SETTINGMODE_BUTTON_VIEW 4
#define SETTINGMODE_EXIT 5
#define MAX_SETTINGMODE 5

#define DRAM_DQ1 14
#define DRAM_DQ2 15
#define DRAM_DQ3 16
#define DRAM_DQ4 17
#define DRAM_Q 14
#define DRAM_D 15
#define DRAM_A0 8
#define DRAM_A1 9
#define DRAM_A2 10
#define DRAM_A3 11
#define DRAM_A4 12
#define DRAM_A5 13
#define DRAM_A6 5
#define DRAM_A7 6
#define DRAM_A8 7
#define DRAM_RAS 2
#define DRAM_CAS 3
#define DRAM_W 4
#define BUTTON A6
#define POW12V A7
//      DRAM_OE GND

#define DRAM_D_PC_SHIFT (DRAM_D - 14)
#define DRAM_Q_PC_SHIFT (DRAM_Q - 14)
#define DRAM_DQ1_PC_SHIFT (DRAM_DQ1 - 14)
#define DRAM_DQ2_PC_SHIFT (DRAM_DQ2 - 14)
#define DRAM_DQ3_PC_SHIFT (DRAM_DQ3 - 14)
#define DRAM_DQ4_PC_SHIFT (DRAM_DQ4 - 14)
#define DRAM_DQ_PC_SHIFT DRAM_DQ1_PC_SHIFT
#define DRAM_A0_PB_SHIFT (DRAM_A0 - 8)
#define DRAM_A1_PB_SHIFT (DRAM_A1 - 8)
#define DRAM_A2_PB_SHIFT (DRAM_A2 - 8)
#define DRAM_A3_PB_SHIFT (DRAM_A3 - 8)
#define DRAM_A4_PB_SHIFT (DRAM_A4 - 8)
#define DRAM_A5_PB_SHIFT (DRAM_A5 - 8)
#define DRAM_A6_PD_SHIFT (DRAM_A6 - 0)
#define DRAM_A7_PD_SHIFT (DRAM_A7 - 0)
#define DRAM_A8_PD_SHIFT (DRAM_A8 - 0)
#define DRAM_A_PB_SHIFT (DRAM_A0 - 8)
#define DRAM_A_PD_SHIFT (DRAM_A6 - 0)
#define DRAM_RAS_PD_SHIFT (DRAM_RAS - 0)
#define DRAM_CAS_PD_SHIFT (DRAM_CAS - 0)
#define DRAM_W_PD_SHIFT (DRAM_W - 0)

#define DRAM_D_PC_MASK _BV(DRAM_D_PC_SHIFT)
#define DRAM_Q_PC_MASK _BV(DRAM_Q_PC_SHIFT)
#define DRAM_DQ_PC_MASK (_BV(DRAM_DQ1_PC_SHIFT) | _BV(DRAM_DQ2_PC_SHIFT) | _BV(DRAM_DQ3_PC_SHIFT) | _BV(DRAM_DQ4_PC_SHIFT))
#define DRAM_A_PB_MASK (_BV(DRAM_A0_PB_SHIFT) | _BV(DRAM_A1_PB_SHIFT) | _BV(DRAM_A2_PB_SHIFT) | _BV(DRAM_A3_PB_SHIFT) | _BV(DRAM_A4_PB_SHIFT) | _BV(DRAM_A5_PB_SHIFT))
#define DRAM_A_PD_MASK (_BV(DRAM_A6_PD_SHIFT) | _BV(DRAM_A7_PD_SHIFT) | _BV(DRAM_A8_PD_SHIFT))
#define DRAM_RAS_PD_MASK _BV(DRAM_RAS_PD_SHIFT)
#define DRAM_CAS_PD_MASK _BV(DRAM_CAS_PD_SHIFT)
#define DRAM_W_PD_MASK _BV(DRAM_W_PD_SHIFT)

#ifdef _BUS_A9_ENABLE
#define DRAM_A9 1
#define DRAM_A9_PD_SHIFT (DRAM_A9 - 0)
#define DRAM_A9_PD_MASK _BV(DRAM_A9_PD_SHIFT)
#endif

#define ANALOG_RESORUTION 1024.0
#define ANALOG_VALUE_LOW_MAX 164

#define VOLTAGE_5V0_MAX (5.0 * 1.05)
#define VOLTAGE_5V0_RATED 5.0
#define VOLTAGE_5V0_MIN (5.0 * 0.95)
#define VOLTAGE_12V0_MAX (12.0 * 1.05)
#define VOLTAGE_12V0_RATED 12.0
#define VOLTAGE_12V0_MIN (12.0 * 0.95)
#define VOLTAGE_3V3_MAX 3.6
#define VOLTAGE_3V3_RATED 3.3
#define VOLTAGE_3V3_MIN 3.0
#define VOLTAGE_12V0_CONVERT_COEFFICIENT (3.0 / ANALOG_RESORUTION)

#define EEPROM_UNERASE_SIZE (EEPROM.length() / 2)
#define EEPROM_IDX_ERASE_TOP (0)
#define EEPROM_IDX_DRAMCONF (EEPROM_IDX_ERASE_TOP + 0)
#define EEPROM_IDX_SPEEDYFLG (EEPROM_IDX_ERASE_TOP + 1)
#define EEPROM_IDX_POWSRCCHKFLG (EEPROM_IDX_ERASE_TOP + 2)
#define EEPROM_IDX_UNERASE_TOP (EEPROM.length() - EEPROM_UNERASE_SIZE)
#define EEPROM_IDX_CALIBVAL (EEPROM_IDX_UNERASE_TOP + 0)

#define MAX_DISP_5X8_LEN (128 / 5)
#define MAX_DISP_9X15_LEN (128 / 9)
#define DRAWNAME_BUF_SIZE (MAX_DISP_9X15_LEN + 1)
#define DRAWTEXT_BUF_SIZE (MAX_DISP_5X8_LEN + 1)

#define _delay_62p5ns asm("nop\n") // 1 clock wait at 16MHz -> 62.5ns
#define _delay_375ns asm("nop\nnop\nnop\nnop\nnop\nnop\n") // 6 clock wait at 16MHz -> 62.5ns x 6 = 375ns

inline int pseudoDigitalRead(uint8_t pin)
{
	return (analogRead(pin) <= ANALOG_VALUE_LOW_MAX) ? 0 : 1;
}

int8_t scene;
int8_t dramConfig;
int8_t settingMode;
byte lastBtn;
unsigned long pressedTime;
int8_t abus_size, nocol, colshift;
int colset, rowset;
bool speedyTest4bit, checkPowerGood5V;
int16_t calibrationValue;
bool powerGood12v, powerGood5v;
volatile double voltage5V0;
volatile double voltage12V0;

void waitButtonPressAndRelease(void)
{
	while (pseudoDigitalRead(BUTTON) == LOW)
		;
	while (pseudoDigitalRead(BUTTON) == HIGH)
		;
	while (pseudoDigitalRead(BUTTON) == LOW)
		;
}

bool checkPowerStatus(void)
{
	int av3v3 = analogRead(BUTTON);
	if (av3v3 > ANALOG_VALUE_LOW_MAX)
	{
		voltage5V0 = (double)calibrationValue / av3v3;
		powerGood5v = (voltage5V0 < VOLTAGE_5V0_MAX && voltage5V0 > VOLTAGE_5V0_MIN);
		voltage12V0 = VOLTAGE_12V0_CONVERT_COEFFICIENT * voltage5V0 * analogRead(POW12V);
		powerGood12v = (voltage12V0 < VOLTAGE_12V0_MAX && voltage12V0 > VOLTAGE_12V0_MIN);
		return true;
	}
	return false;
}

void setup(void)
{
	dispInit();
	disableDramBus();
#if 0
	// Caribration Value (3V3 actual voltage * 1024) write to EEPROM
	calibrationValue = 3.300 * ANALOG_RESORUTION;
	for (uint16_t i = 0; i < EEPROM.length(); i++)
	{
		EEPROM.update(i, -1);
	}
	EEPROM.put(EEPROM_IDX_CALIBVAL, calibrationValue);
#endif
	powerGood12v = false;
	powerGood5v = false;
	voltage5V0 = 0.0;
	voltage12V0 = 0.0;
	dramConfig = EEPROM.read(EEPROM_IDX_DRAMCONF);
	dramConfig = (dramConfig > MAX_DRAMCONF || dramConfig < MIN_DRAMCONF) ? DRAMCONF_64X1 : dramConfig;
	speedyTest4bit = (EEPROM.read(EEPROM_IDX_SPEEDYFLG) != 0);
	checkPowerGood5V = (EEPROM.read(EEPROM_IDX_POWSRCCHKFLG) != 0);

	EEPROM.get(EEPROM_IDX_CALIBVAL, calibrationValue);
	calibrationValue = calibrationValue > (int16_t)(VOLTAGE_3V3_MAX * ANALOG_RESORUTION) || calibrationValue < (int16_t)(VOLTAGE_3V3_MIN * ANALOG_RESORUTION) ? (int16_t)(VOLTAGE_3V3_RATED * ANALOG_RESORUTION) : calibrationValue;
	lastBtn = pseudoDigitalRead(BUTTON);
	if (lastBtn == LOW)
	{ // button is pressed
		settingMode = SETTINGMODE_TESTTYPE_CHG;
		settingModeDisp();
		scene = SCENE_SETTING_SELECT_ENTER;
	}
	else
	{
		checkPowerStatus();
		dramConfSelectDisp(false);
		lastBtn = LOW;
		scene = SCENE_DRAMCONF_SELECT_ENTER;
	}
}

void loop(void)
{
	unsigned long pressDuration;
	byte currentBtn;

	switch (scene)
	{
	case SCENE_SETTING_SELECT_ENTER:
		currentBtn = pseudoDigitalRead(BUTTON);
		if (lastBtn == LOW && currentBtn == HIGH)
		{ // button is released
			checkPowerStatus();
			lastBtn = HIGH;
			settingModeDisp();
			scene = SCENE_SETTING_SELECT;
		}
		break;
	case SCENE_SETTING_SELECT:
		currentBtn = pseudoDigitalRead(BUTTON);
		if (lastBtn == HIGH && currentBtn == LOW)
		{ // button is pressed
			lastBtn = LOW;
			pressedTime = millis();
		}
		pressDuration = millis() - pressedTime;
		if (lastBtn == LOW && currentBtn == HIGH)
		{ // button is released
			checkPowerStatus();
			lastBtn = HIGH;
			if (pressDuration < 1500)
			{ // short press
				settingMode++;
				settingMode = (settingMode > MAX_SETTINGMODE) ? MIN_SETTINGMODE : settingMode;
				settingModeDisp();
			}
		}
		if (lastBtn == LOW && currentBtn == LOW && pressDuration > 1500)
		{ // long press
			switch (settingMode)
			{
			case SETTINGMODE_TESTTYPE_CHG:
				speedyTest4bit = !speedyTest4bit;
				settingModeDisp();
				scene = SCENE_SETTING_SELECT_ENTER;
				break;
			case SETTINGMODE_POWSRCCHK_CHG:
				checkPowerGood5V = !checkPowerGood5V;
				settingModeDisp();
				scene = SCENE_SETTING_SELECT_ENTER;
				break;
			case SETTINGMODE_EEPROM_ERASE:
				eraseEepromDisp(false);
				for (uint16_t idx = 0; idx < EEPROM_IDX_UNERASE_TOP; idx++)
				{
					EEPROM.update(idx, -1);
				}
				speedyTest4bit = true;
				checkPowerGood5V = true;
				eraseEepromDisp(true);
				scene = SCENE_DRAMCONF_SELECT_ENTER;
				dramConfSelectDisp(false);
				break;
			case SETTINGMODE_POWER12V_VIEW:
				check12vModeDisp();
				scene = SCENE_VIEW_12V;
				break;
			case SETTINGMODE_BUTTON_VIEW:
				checkButtonModeDisp();
				scene = SCENE_VIEW_BTN;
				break;
			case SETTINGMODE_EXIT:
				if ((EEPROM.read(EEPROM_IDX_SPEEDYFLG) != 0 && !speedyTest4bit) || (EEPROM.read(EEPROM_IDX_SPEEDYFLG) == 0 && speedyTest4bit))
				{
					EEPROM.write(EEPROM_IDX_SPEEDYFLG, speedyTest4bit);
				}
				if ((EEPROM.read(EEPROM_IDX_POWSRCCHKFLG) != 0 && !checkPowerGood5V) || (EEPROM.read(EEPROM_IDX_POWSRCCHKFLG) == 0 && checkPowerGood5V))
				{
					EEPROM.write(EEPROM_IDX_POWSRCCHKFLG, checkPowerGood5V);
				}
				scene = SCENE_DRAMCONF_SELECT_ENTER;
				dramConfSelectDisp(false);
				break;
			}
		}
		break;
	case SCENE_VIEW_12V:
		checkPowerStatus();
		check12vModeDisp();
		scene = SCENE_VIEW_12V;
		break;
	case SCENE_VIEW_BTN:
		checkPowerStatus();
		checkButtonModeDisp();
		scene = SCENE_VIEW_BTN;
		break;
	case SCENE_DRAMCONF_SELECT_ENTER:
		currentBtn = pseudoDigitalRead(BUTTON);
		if (currentBtn == HIGH)
		{ // button is released
			lastBtn = HIGH;
			checkPowerStatus();
			dramConfSelectDisp(false);
			scene = SCENE_DRAMCONF_SELECT;
		}
		break;
	case SCENE_DRAMCONF_SELECT:
		currentBtn = pseudoDigitalRead(BUTTON);
		if (lastBtn == HIGH && currentBtn == LOW)
		{ // button is pressed
			lastBtn = LOW;
			pressedTime = millis();
		}
		pressDuration = millis() - pressedTime;
		if (lastBtn == LOW && currentBtn == HIGH)
		{ // button is released
			checkPowerStatus();
			lastBtn = HIGH;
			if (pressDuration < 1500)
			{ // short press
				dramConfig++;
				dramConfig = (dramConfig > MAX_DRAMCONF) ? MIN_DRAMCONF : dramConfig;
				dramConfSelectDisp(false);
			}
		}
		if (lastBtn == LOW && currentBtn == LOW && pressDuration > 1500)
		{ // long press
			dramConfSelectDisp(true);
			scene = SCENE_DRAM_TEST_ENTER;
		}
		break;
	case SCENE_DRAM_TEST_ENTER:
		currentBtn = pseudoDigitalRead(BUTTON);
		if (currentBtn == HIGH)
		{ // button is released
			lastBtn = HIGH;
			checkPowerStatus();
			if (!powerGood12v && dramConfig == DRAMCONF_16X1)
			{
				failedPower12vDisp();
				dramConfSelectDisp(false);
				scene = SCENE_DRAMCONF_SELECT_ENTER;
				break;
			}
			if (!powerGood5v && checkPowerGood5V)
			{
				failedPower5vDisp();
				dramConfSelectDisp(false);
				scene = SCENE_DRAMCONF_SELECT_ENTER;
				break;
			}
			dramConfSelectDisp(false);
			scene = SCENE_DRAM_TEST;
		}
		break;
	case SCENE_DRAM_TEST:
		EEPROM.update(EEPROM_IDX_DRAMCONF, dramConfig);
#ifndef _DEMO_MODE
		startDramTest();
#else
		passedTestDisp();
#endif
		scene = SCENE_DRAMCONF_SELECT_ENTER;
		break;
	}
}

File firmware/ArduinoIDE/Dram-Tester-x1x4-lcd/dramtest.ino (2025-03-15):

inline void prepareTest4(void)
{
	// PC0-PC3 Input, PC4-PC6 keep state
	// (Since the settings change when getDataBus4() and setDataBus4() are executed, the settings here are normally unnecessary.)
	DDRC &= ~DRAM_DQ_PC_MASK;
}

inline void prepareWrite4(void)
{
	// PC0-PC3 Output, PC4-PC6 keep state
	DDRC |= DRAM_DQ_PC_MASK;
	/*
	pinMode(DRAM_DQ1, OUTPUT);
	pinMode(DRAM_DQ2, OUTPUT);
	pinMode(DRAM_DQ3, OUTPUT);
	pinMode(DRAM_DQ4, OUTPUT);
	*/
}

inline void setDataBus4(int value)
{
	PORTC = (PORTC & ~DRAM_DQ_PC_MASK) | ((value << DRAM_DQ_PC_SHIFT) & DRAM_DQ_PC_MASK);
	/*
	digitalWrite(DRAM_DQ1, (value >> 0) & 1);
	digitalWrite(DRAM_DQ2, (value >> 1) & 1);
	digitalWrite(DRAM_DQ3, (value >> 2) & 1);
	digitalWrite(DRAM_DQ4, (value >> 3) & 1);
	*/
}

inline void prepareRead4(void)
{
	// PC0-PC3 Not pull-up, PC4-PC6 keep state
	// Clearing the pull-up setting is required regardless of whether the pinMode() function is used. (Test will start without any IC inserted into the socket.)
	PORTC &= ~DRAM_DQ_PC_MASK;
	// PC0-PC3 Input, PC4-PC6 keep state
	DDRC &= ~DRAM_DQ_PC_MASK;
	/*
	PORTC &= ~DRAM_DQ_PC_MASK;
	pinMode(DRAM_DQ1, INPUT);
	pinMode(DRAM_DQ2, INPUT);
	pinMode(DRAM_DQ3, INPUT);
	pinMode(DRAM_DQ4, INPUT);
	*/
}

inline int getDataBus4(void)
{
	// PC0-3 to return value bit0-3
	return (PINC & DRAM_DQ_PC_MASK) >> DRAM_DQ_PC_SHIFT;
	/*
	return	(digitalRead(DRAM_DQ1) << 0) |
			(digitalRead(DRAM_DQ2) << 1) |
			(digitalRead(DRAM_DQ3) << 2) |
			(digitalRead(DRAM_DQ4) << 3);
	*/
}

inline void prepareTest1(void)
{
	// PC0 Not pull-up, PC1-PC6 keep state
	// Clearing the pull-up setting is required regardless of whether the pinMode() function is used. (Test will start without any IC inserted into the socket.)
	PORTC &= ~DRAM_Q_PC_MASK;
	// PC0 Input, PC1 Output, PC2-PC6 keep state
	DDRC = (DDRC & ~DRAM_Q_PC_MASK) | DRAM_D_PC_MASK;
	/*
	pinMode(DRAM_Q, INPUT);
	pinMode(DRAM_D, OUTPUT);
	*/
}

inline void prepareWrite1(void)
{
	// PC1 Output, PC0 & PC2-PC6 keep state
	// (Since the settings are fixed from prepareTest1(), the settings here are originally unnecessary.)
	DDRC |= DRAM_D_PC_MASK;
	/*
	pinMode(DRAM_D, OUTPUT);
	*/
}

inline void setDataBus1(int value)
{
	PORTC = (PORTC & ~DRAM_D_PC_MASK) | ((value << DRAM_D_PC_SHIFT) & DRAM_D_PC_MASK);
	/*
	digitalWrite(DRAM_D, value & 1);
	*/
}

inline void prepareRead1(void)
{
	// PC0 Input, PC1-PC6 keep state
	// (Since the settings are fixed from prepareTest1(), the settings here are originally unnecessary.)
	DDRC &= ~DRAM_Q_PC_MASK;
	/*
	pinMode(DRAM_Q, INPUT);
	*/
}

inline int getDataBus1(void)
{
	return (PINC & DRAM_Q_PC_MASK) >> DRAM_Q_PC_SHIFT;
	/*
	return digitalRead(DRAM_Q);
	*/
}

inline void enableDramBus(void)
{
#ifndef _BUS_A9_ENABLE
	// PD2-PD7 Output, PD0-PD1 keep state
	DDRD |= DRAM_A_PD_MASK | DRAM_RAS_PD_MASK | DRAM_CAS_PD_MASK | DRAM_W_PD_MASK;
#else
	// PD1-PD7 Output, PD0 keep state
	DDRD |= DRAM_A_PD_MASK | DRAM_RAS_PD_MASK | DRAM_CAS_PD_MASK | DRAM_W_PD_MASK | DRAM_A9_PD_MASK;
#endif
	// PD2-PD4 HIGH, PD0-PD1 & PD5-PD7 keep state
	PORTD |= DRAM_W_PD_MASK | DRAM_CAS_PD_MASK | DRAM_RAS_PD_MASK;
	// PB0-PB5 Output, other bits keep state
	DDRB |= DRAM_A_PB_MASK;
	// PC0-PC3 Not pull-up, PC4-PC5 & other bits keep state
	PORTC &= ~DRAM_DQ_PC_MASK;
	// PC0-PC3 Input, PC4-PC5 & other bits keep state
	DDRC &= ~DRAM_DQ_PC_MASK;
	/*
	for (int pin = 2; pin < 14; pin++)
		pinMode(pin, OUTPUT);
#ifdef _BUS_A9_ENABLE
	pinMode(DRAM_A9, OUTPUT);
#endif
	digitalWrite(DRAM_W, HIGH);
	digitalWrite(DRAM_CAS, HIGH);
	digitalWrite(DRAM_RAS, HIGH);
	for (int pin = 14; pin < 18; pin++)
		pinMode(pin, INPUT);
	*/
}

inline void disableDramBus(void)
{
#ifndef _BUS_A9_ENABLE
	// PD2-PD7 Not pull-up, PD0-1 keep state
	PORTD &= ~(DRAM_A_PD_MASK | DRAM_RAS_PD_MASK | DRAM_CAS_PD_MASK | DRAM_W_PD_MASK);
	// PD2-PD7 Input, PD0-1 keep state
	DDRD &= ~(DRAM_A_PD_MASK | DRAM_RAS_PD_MASK | DRAM_CAS_PD_MASK | DRAM_W_PD_MASK);
#else
	// PD1-PD7 Not pull-up, PD0-1 keep state
	PORTD &= ~(DRAM_A_PD_MASK | DRAM_RAS_PD_MASK | DRAM_CAS_PD_MASK | DRAM_W_PD_MASK | DRAM_A9_PD_MASK);
	// PD1-PD7 Input, PD0 keep state
	DDRD &= ~(DRAM_A_PD_MASK | DRAM_RAS_PD_MASK | DRAM_CAS_PD_MASK | DRAM_W_PD_MASK | DRAM_A9_PD_MASK);
#endif
	// PB0-PB5 Not pull-up, other bits keep state
	PORTB &= ~DRAM_A_PB_MASK;
	// PB0-PB5 Input, other bits keep state
	DDRB &= ~DRAM_A_PB_MASK;
	// PC0-PC3 Not pull-up, PC4-PC5 & other bits keep state
	PORTC &= ~DRAM_DQ_PC_MASK;
	// PC0-PC3 Input, PC4-PC5 & other bits keep state
	DDRC &= ~DRAM_DQ_PC_MASK;
	/*
	for (int pin = 2; pin < 18; pin++)
		pinMode(pin, INPUT);
#ifdef _BUS_A9_ENABLE
	pinMode(DRAM_A9, INPUT);
#endif
	*/
}

inline void setAddressBus(int adr)
{
	// bit0-5 to PB0-5
	PORTB = (PORTB & ~DRAM_A_PB_MASK) | (((adr >> 0) << DRAM_A_PB_SHIFT) & DRAM_A_PB_MASK);
#ifndef _BUS_A9_ENABLE
	// bit6-8 to PD5-7
	PORTD = (PORTD & ~DRAM_A_PD_MASK) | (((adr >> 6) << DRAM_A_PD_SHIFT) & DRAM_A_PD_MASK);
#else
	// bit6-8 to PD5-7, bit9 to PD1
	PORTD = (PORTD & ~(DRAM_A_PD_MASK | DRAM_A9_PD_MASK)) | (((adr >> 6) << DRAM_A_PD_SHIFT) & DRAM_A_PD_MASK) | (((adr >> 9) << DRAM_A9_PD_SHIFT) & DRAM_A9_PD_MASK);
#endif
	/*
	digitalWrite(DRAM_A0, (adr >> 0) & 1);
	digitalWrite(DRAM_A1, (adr >> 1) & 1);
	digitalWrite(DRAM_A2, (adr >> 2) & 1);
	digitalWrite(DRAM_A3, (adr >> 3) & 1);
	digitalWrite(DRAM_A4, (adr >> 4) & 1);
	digitalWrite(DRAM_A5, (adr >> 5) & 1);
	digitalWrite(DRAM_A6, (adr >> 6) & 1);
	digitalWrite(DRAM_A7, (adr >> 7) & 1);
	digitalWrite(DRAM_A8, (adr >> 8) & 1);
#ifdef _BUS_A9_ENABLE
	digitalWrite(DRAM_A9, (adr >> 9) & 1);
#endif
	*/
}

inline void writeDram1(int row, int col, int value)
{
	prepareWrite1();
	setAddressBus(row);
	PORTD &= ~DRAM_RAS_PD_MASK;
	PORTD &= ~DRAM_W_PD_MASK;
	/*
	digitalWrite(DRAM_RAS, LOW);
	digitalWrite(DRAM_W, LOW);
	*/
	setDataBus1(value);
	setAddressBus(col);
	PORTD &= ~DRAM_CAS_PD_MASK;
	_delay_375ns;
	PORTD |= DRAM_W_PD_MASK;
	PORTD |= DRAM_CAS_PD_MASK;
	PORTD |= DRAM_RAS_PD_MASK;
	/*
	digitalWrite(DRAM_CAS, LOW);
	digitalWrite(DRAM_W, HIGH);
	digitalWrite(DRAM_CAS, HIGH);
	digitalWrite(DRAM_RAS, HIGH);
	*/
}

inline void writeDram4(int row, int col, int value)
{
	prepareWrite4();
	setAddressBus(row);
	PORTD &= ~DRAM_RAS_PD_MASK;
	PORTD &= ~DRAM_W_PD_MASK;
	/*
	digitalWrite(DRAM_RAS, LOW);
	digitalWrite(DRAM_W, LOW);
	*/
	setDataBus4(value);
	setAddressBus(col);
	PORTD &= ~DRAM_CAS_PD_MASK;
	_delay_375ns;
	PORTD |= DRAM_W_PD_MASK;
	PORTD |= DRAM_CAS_PD_MASK;
	PORTD |= DRAM_RAS_PD_MASK;
	/*
	digitalWrite(DRAM_CAS, LOW);
	digitalWrite(DRAM_W, HIGH);
	digitalWrite(DRAM_CAS, HIGH);
	digitalWrite(DRAM_RAS, HIGH);
	*/
}
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

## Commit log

2024-03-16 First Release
    First release distribution version.
    [Dram-Tester-x1x4-lcd.csv, Dram-Tester-x1x4-lcd.kicad_pcb, Dram-Tester-x1x4-lcd.kicad_sch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]
2024-03-16 Modified README
    Modified README
    Add forward voltage to LED in BOM & parts list.
    [bom.xlsx]
2024-03-24 Modified README
    ACDC adapter voltage correction and 12V voltage display note added.
    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
2025-03-15 Added support for MB8265A type DRAM
    MB8265A(1ピンが負論理のREFRESH信号である)タイプのDRAMのサポートを追加。
    Added support for MB8265A (pin 1 is a negative logic refresh signal) type DRAM.
    [arduino_nano-pin_assign.xlsx, dram-pin_assign.xlsx]
2025-03-23 Schematic modified
    回路図を修正
    Schematic modified.
    積層セラミックコンデンサのピッチを2.5mmに変更
    Changed pitch of MLCC to 2.5 mm.
    未実装の5V-DCDCモジュールを削除
    Remove unmounted 5V-DCDC module
    重複していたパスコンを削除
    Removed duplicated bypass capacitor.
    47μFの電解コンデンサを10μFに変更
    47uF ELC changed to 10uF.
    チャージポンプの品番をTC7660SからTJ7660に変更
    The part number of the charge pump was changed from TC7660S to TJ7660.
    その他細かな修正
    Other minor modifications.
    [Dram-Tester-x1x4-lcd.csv, Dram-Tester-x1x4-lcd.kicad_pcb, Dram-Tester-x1x4-lcd.kicad_sch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]
2025-03-23 README.md modified
    README.mdを修正
    README.md modified.
    部品表が更新されていなかったため更新
    Updated the parts list because it had not been updated.
2025-03-23 README.md modified.
    部品表が正しく更新されていなかったため再更新
    The parts list was not updated correctly so it was updated again.
    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
2025-04-22 Modified README
    READMEに完成品の写真を貼り付けた
    I've attached a photo of the finished product in the README.
    READMEに組み立て方の項目を追加した
    Added assembly instructions to the README.
2025-04-28 Modified README
    READMEの準備の項目に電圧補正値の書き込み手順を追加しました
    Added instructions for writing voltage compensation values to the preparation section of the README.
2025-04-28 Modified README
    ACアダプタの出力電流値が1A必要である旨を追記
    Added that the ACDC adapter requires an output current of 1A.
2025-04-29 Modified README
    細かな文言の修正
    Minor wording corrections.
2025-06-06 Modified Schematic & README
    Modified Schematic & README
    回路図および基板のリビジョンを4に更新し部品番号のシルク印刷の欠落を修正
    Updated schematic and PCB revision to 4 and fixed missing part number silkscreen.
    READMEの準備項に頒布品に関する記載を追加
    Added information about distribution items to the preparation section of the README.
    [Dram-Tester-x1x4-lcd.kicad_pcb, Dram-Tester-x1x4-lcd.kicad_sch, positions.csv]
